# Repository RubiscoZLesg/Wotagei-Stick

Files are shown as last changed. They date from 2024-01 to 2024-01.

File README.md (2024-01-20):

# 可变色充电式电子荧光棒
WOTA艺打师永業参上！ 骗个关注先~ \
https://space.bilibili.com/18416307?spm_id_from=333.1007.0.0 \
因为目前市面上可充电电棒各有千秋（参差不齐），不是很符合个人平时练习需求，于是就自己做了个。 \
成本相当低廉，外壳使用了外径18mm，壁厚1.5mm，长20cm的透明PC管，PCB与3D打印零件均由嘉立创打样制作，如果领了券的话，一对大概能以20元价格拿下。 \
另外为了脱机控制颜色，制作了控制板，成本大概在5元左右，界面不甚优雅，突出一个能用就行。

## 光棒
主控采用了STC8G，驱动12颗WS2812灯珠，供电采用单节14500电池，长按开关机。为防止误触与增加稳定性，开关做在了顶部，但尺寸选的不太好（手里有于是就没买别的） \
为了保存颜色，MCU一旦上电就不会掉电，但整板采用了低功耗设计，静态功耗在uA级，充满电后也可以连续正常使用2小时以上。

- 光棒效果
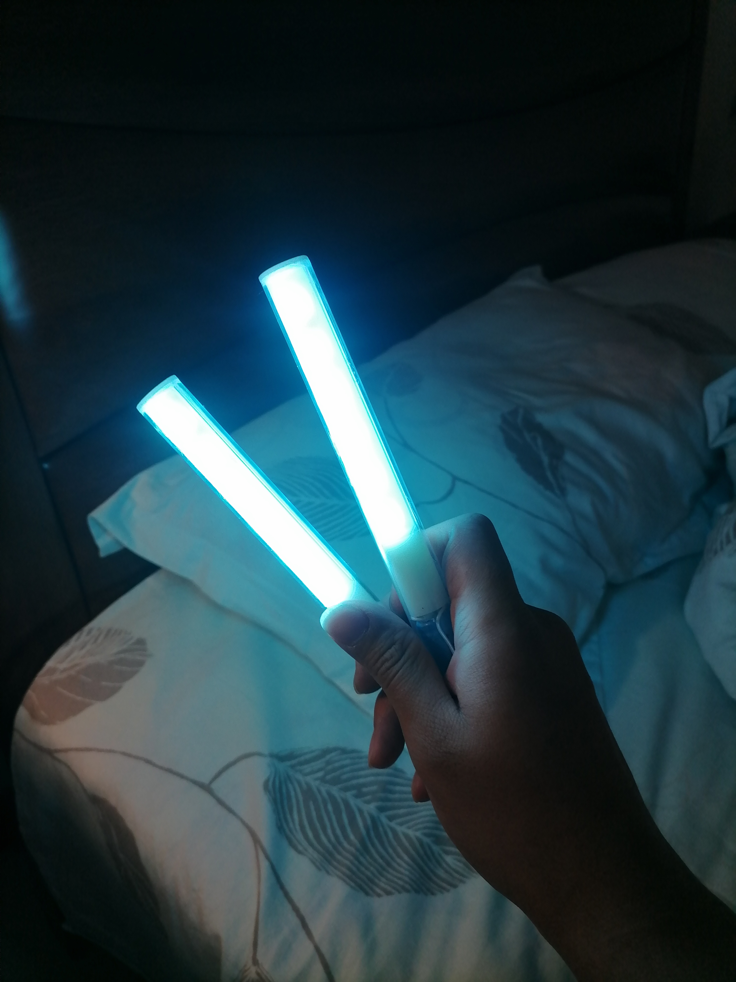
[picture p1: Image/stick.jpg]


- 充电效果
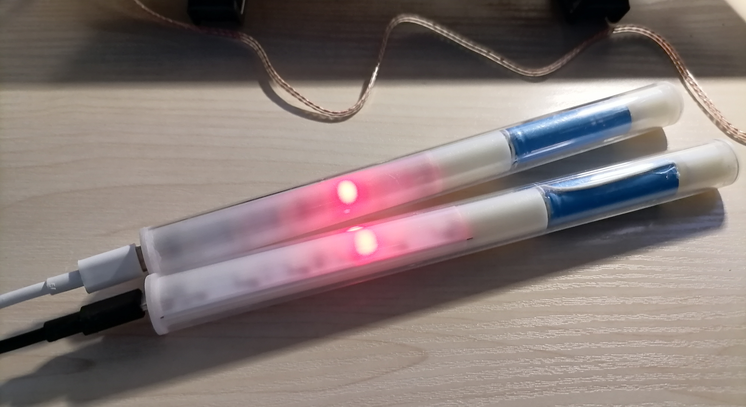
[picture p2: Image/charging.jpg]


- 灯板正反面
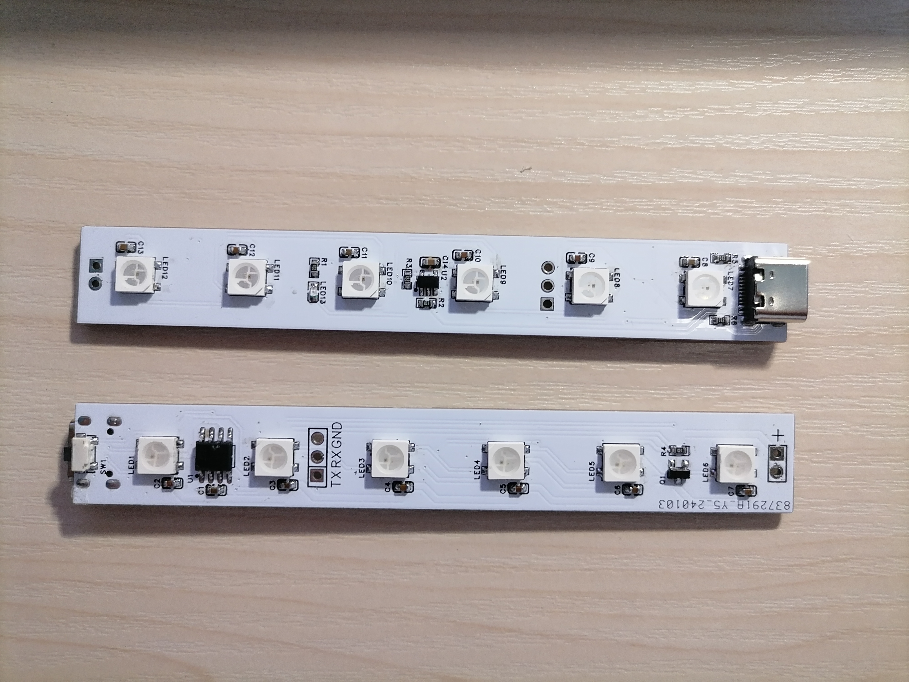
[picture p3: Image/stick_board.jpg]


## 控制板
主控采用了STM32G030，带一块0.96寸IPS，颜色控制数据传输采用了串口（USB两个数据线一根TX一根RX）,也是能充电的。

- 正面长这样
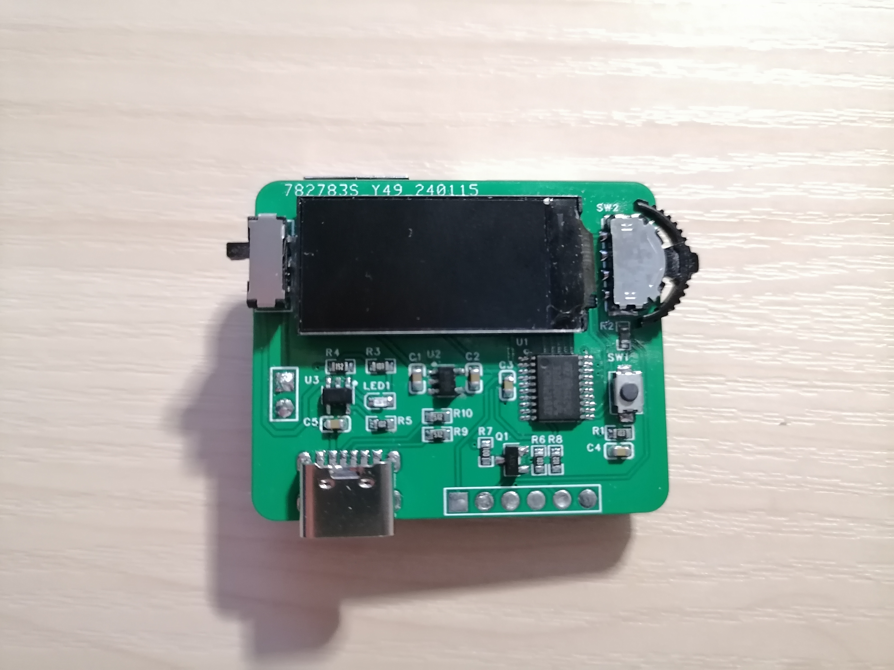
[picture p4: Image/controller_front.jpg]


- 背面长这样（TYPE-A座子再插TYPE-C线属实不够优雅，但手头刚好有而且好焊）
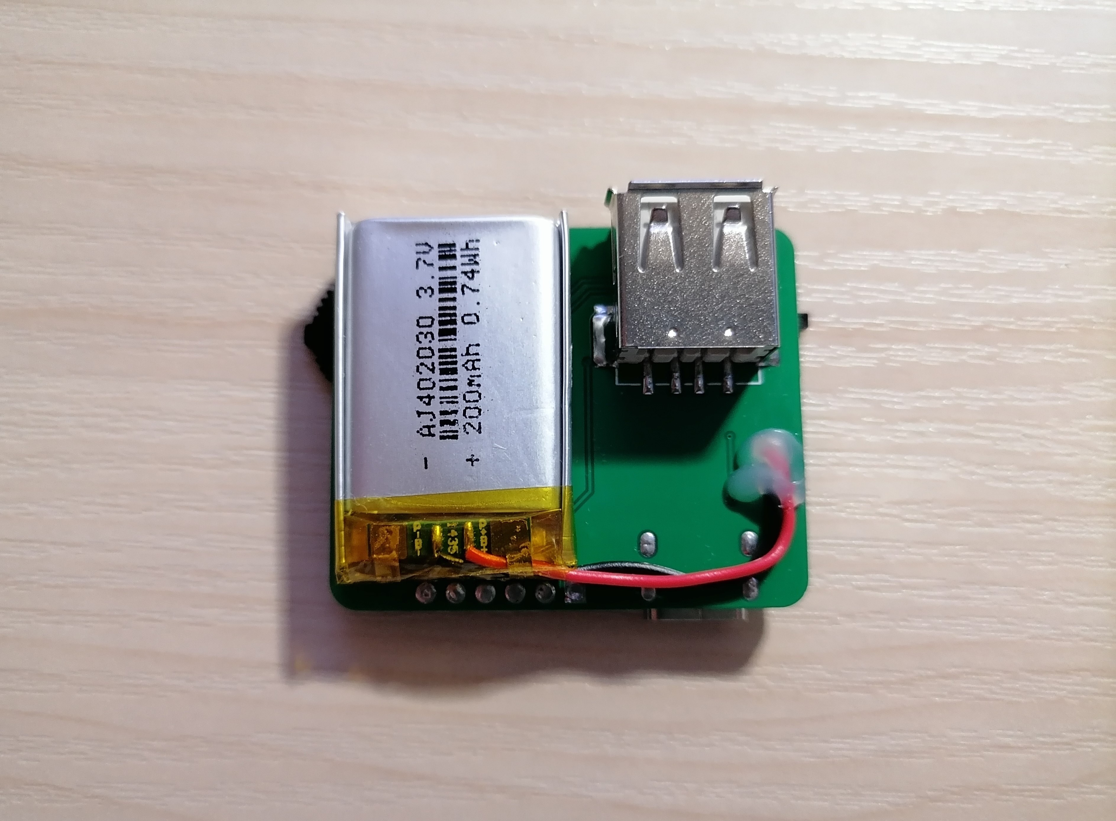
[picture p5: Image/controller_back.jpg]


- 屏幕界面
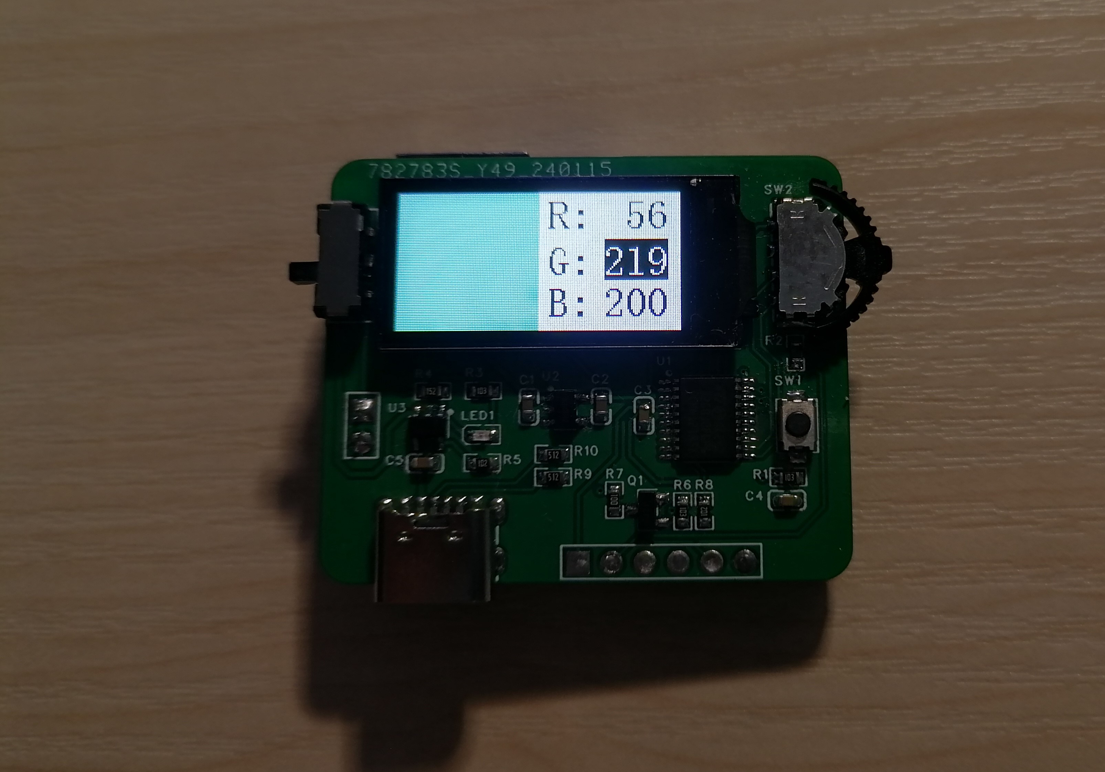
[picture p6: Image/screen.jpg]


## 制作方法
Gerber文件夹中有各个部分的Gerber文件，交付板厂就能直接打样，光棒灯板板厚要选`1.0mm`。 \
Model文件夹中是外壳零件的STL文件，可直接3D打印。 \
Frimware文件夹中是光棒的hex固件，使用`STC-ISP`烧录，烧录时工作频率选择`24MHz`。 \
Hardware文件夹中提供了立创EDA与AD（立创EDA导出的hh）两种PCB工程文件，方便各位查看。 \
Sourse中存放了源码（waring: 注释不多），分别是`Keil`与`STM32CubeIDE`工程文件，仅供参考，如有更好的实现方法欢迎交流。

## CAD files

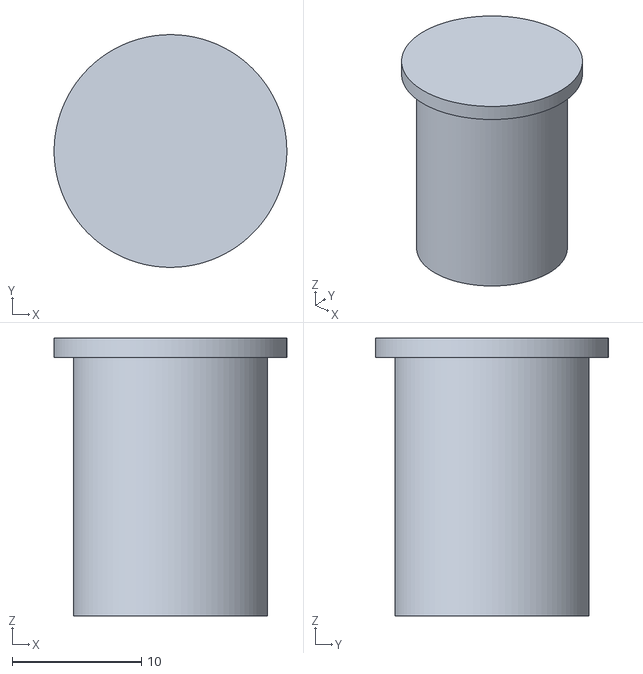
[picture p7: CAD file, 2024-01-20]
Model/3DShell_3DShell_WotageiStick_T_3.stl
18.0 x 18.0 x 21.5

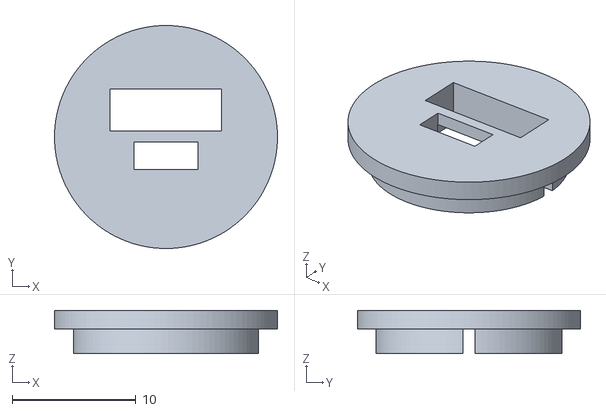
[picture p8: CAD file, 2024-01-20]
Model/3DShell_3DShell_WotageiStick_T_2.stl
18.0 x 18.0 x 3.50

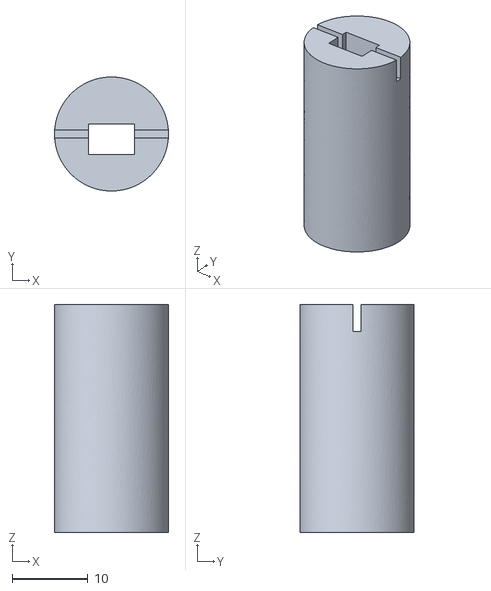
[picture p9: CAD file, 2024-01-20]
Model/3DShell_3DShell_WotageiStick_T_4.stl
15.0 x 15.0 x 30.0

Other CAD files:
Source/Wotagei_Stick/Objects/main.obj

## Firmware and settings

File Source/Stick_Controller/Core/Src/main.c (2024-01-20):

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
/* Includes ------------------------------------------------------------------*/
#include "main.h"
#include "spi.h"
#include "usart.h"
#include "gpio.h"

/* USER CODE BEGIN Includes */
#include "lcd_init.h"
#include "lcd.h"
#include "stdio.h"
/* USER CODE END Includes */


/* USER CODE BEGIN PV */
uint16_t Rdat = 255, Gdat, Bdat;
uint8_t State;
uint8_t Sel_Cnt;
uint8_t Sel_Flag = 1, Adj_Flag;
/* USER CODE END PV */

void SystemClock_Config(void);
/**
  * @brief  The application entry point.
  * @retval int
  */
int main(void)
{
  /* MCU Configuration--------------------------------------------------------*/

  /* Reset of all peripherals, Initializes the Flash interface and the Systick. */
  HAL_Init();

  /* Configure the system clock */
  SystemClock_Config();

  /* Initialize all configured peripherals */
  MX_GPIO_Init();
  MX_SPI1_Init();
  MX_USART1_UART_Init();
  /* USER CODE BEGIN 2 */
  LCD_Init();
  LCD_Fill(0, 0, LCD_W/2, LCD_H, RED);
  LCD_Fill(LCD_W/2-1, 0, LCD_W, LCD_H, WHITE);
  LCD_ShowString(LCD_W/2+5, 0, (uint8_t *)"R:", BLACK, WHITE, 24, 0);
  LCD_ShowString(LCD_W/2+5, 27, (uint8_t *)"G:", BLACK, WHITE, 24, 0);
  LCD_ShowString(LCD_W/2+5, 51, (uint8_t *)"B:", BLACK, WHITE, 24, 0);
  LCD_ShowIntNum(LCD_W/2+37, 0, Rdat, 3, WHITE, BLACK, 24);
  LCD_ShowIntNum(LCD_W/2+37, 27, Gdat, 3, BLACK, WHITE, 24);
  LCD_ShowIntNum(LCD_W/2+37, 51, Bdat, 3, BLACK, WHITE, 24);
  /* USER CODE END 2 */

  /* Infinite loop */
  /* USER CODE BEGIN WHILE */
  while (1)
  {
	  if (State == 0)
	  {
		  if (Sel_Flag)
		  {
			  Sel_Flag = 0;
			  switch (Sel_Cnt)
			  {
			  case 0:
				  LCD_ShowIntNum(LCD_W/2+37, 0, Rdat, 3, WHITE, BLACK, 24);
				  LCD_ShowIntNum(LCD_W/2+37, 27, Gdat, 3, BLACK, WHITE, 24);
				  LCD_ShowIntNum(LCD_W/2+37, 51, Bdat, 3, BLACK, WHITE, 24);
				  break;
			  case 1:
				  LCD_ShowIntNum(LCD_W/2+37, 0, Rdat, 3, BLACK, WHITE, 24);
				  LCD_ShowIntNum(LCD_W/2+37, 27, Gdat, 3, WHITE, BLACK, 24);
				  LCD_ShowIntNum(LCD_W/2+37, 51, Bdat, 3, BLACK, WHITE, 24);
				  break;
			  case 2:
				  LCD_ShowIntNum(LCD_W/2+37, 0, Rdat, 3, BLACK, WHITE, 24);
				  LCD_ShowIntNum(LCD_W/2+37, 27, Gdat, 3, BLACK, WHITE, 24);
				  LCD_ShowIntNum(LCD_W/2+37, 51, Bdat, 3, WHITE, BLACK, 24);
				  break;
			  }
		  }
	  }
	  else
	  {
		  if (Adj_Flag)
		  {
			  Adj_Flag = 0;
			  switch (Sel_Cnt)
			  {
			  case 0:
				  while (HAL_GPIO_ReadPin(SW_UP_GPIO_Port, SW_UP_Pin) == GPIO_PIN_RESET)
				  {
					  if (Rdat < 255)
					  {
						  Rdat++;
						  LCD_ShowIntNum(LCD_W/2+37, 0, Rdat, 3, WHITE, BLACK, 24);
						  LCD_Fill(0, 0, LCD_W/2, LCD_H, ((Rdat >> 3) << 11) + ((Gdat >> 2) << 5) + (Bdat >> 3));
					  }
				  }
				  while (HAL_GPIO_ReadPin(SW_DN_GPIO_Port, SW_DN_Pin) == GPIO_PIN_RESET)
				  {
					  if (Rdat > 0)
					  {
						  Rdat--;
						  LCD_ShowIntNum(LCD_W/2+37, 0, Rdat, 3, WHITE, BLACK, 24);
						  LCD_Fill(0, 0, LCD_W/2, LCD_H, ((Rdat >> 3) << 11) + ((Gdat >> 2) << 5) + (Bdat >> 3));
					  }
				  }
				  break;
			  case 1:
				  while (HAL_GPIO_ReadPin(SW_UP_GPIO_Port, SW_UP_Pin) == GPIO_PIN_RESET)
				  {
					  if (Gdat < 255)
					  {
						  Gdat++;
						  LCD_ShowIntNum(LCD_W/2+37, 27, Gdat, 3, WHITE, BLACK, 24);
						  LCD_Fill(0, 0, LCD_W/2, LCD_H, ((Rdat >> 3) << 11) + ((Gdat >> 2) << 5) + (Bdat >> 3));
					  }
				  }
				  while (HAL_GPIO_ReadPin(SW_DN_GPIO_Port, SW_DN_Pin) == GPIO_PIN_RESET)
				  {
					  if (Gdat > 0)
					  {
						  Gdat--;
						  LCD_ShowIntNum(LCD_W/2+37, 27, Gdat, 3, WHITE, BLACK, 24);
						  LCD_Fill(0, 0, LCD_W/2, LCD_H, ((Rdat >> 3) << 11) + ((Gdat >> 2) << 5) + (Bdat >> 3));
					  }
				  }
				  break;
			  case 2:
				  while (HAL_GPIO_ReadPin(SW_UP_GPIO_Port, SW_UP_Pin) == GPIO_PIN_RESET)
				  {
					  if (Bdat < 255)
					  {
						  Bdat++;
						  LCD_ShowIntNum(LCD_W/2+37, 51, Bdat, 3, WHITE, BLACK, 24);
						  LCD_Fill(0, 0, LCD_W/2, LCD_H, ((Rdat >> 3) << 11) + ((Gdat >> 2) << 5) + (Bdat >> 3));
					  }
				  }
				  while (HAL_GPIO_ReadPin(SW_DN_GPIO_Port, SW_DN_Pin) == GPIO_PIN_RESET)
				  {
					  if (Bdat > 0)
					  {
						  Bdat--;
						  LCD_ShowIntNum(LCD_W/2+37, 51, Bdat, 3, WHITE, BLACK, 24);
						  LCD_Fill(0, 0, LCD_W/2, LCD_H, ((Rdat >> 3) << 11) + ((Gdat >> 2) << 5) + (Bdat >> 3));
					  }
				  }
				  break;
			  }
		  }
	  }
    /* USER CODE END WHILE */

    /* USER CODE BEGIN 3 */
  }
  /* USER CODE END 3 */
}

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
/* USER CODE BEGIN 4 */
void HAL_GPIO_EXTI_Falling_Callback(uint16_t GPIO_Pin)
{
	uint8_t trans_buf[4] = {0};
	if(GPIO_Pin == SW_OK_Pin)
	{
		HAL_Delay(10);
        if (HAL_GPIO_ReadPin(SW_OK_GPIO_Port, SW_OK_Pin) == GPIO_PIN_RESET)
        {
        	if (State == 0)
        	{
        		State = 1;
        	}
        	else
        	{
        		State = 0;
        		trans_buf[0] = Rdat;
        		trans_buf[1] = Gdat;
        		trans_buf[2] = Bdat;
        		HAL_UART_Transmit(&huart1, trans_buf, 4, HAL_MAX_DELAY);
        	}

        }
	}
	else if(GPIO_Pin == SW_UP_Pin)
	{
		HAL_Delay(10);
        if (HAL_GPIO_ReadPin(SW_UP_GPIO_Port, SW_UP_Pin) == GPIO_PIN_RESET)
        {
        	if (State == 0)
        	{
        		if (Sel_Cnt > 0)
        		{
        			Sel_Flag = 1;
        			Sel_Cnt--;
        		}
        	}
        	else
        	{
        		Adj_Flag = 1;
        	}
        }
	}
	else if(GPIO_Pin == SW_DN_Pin)
	{
		HAL_Delay(10);
        if (HAL_GPIO_ReadPin(SW_DN_GPIO_Port, SW_DN_Pin) == GPIO_PIN_RESET)
        {
        	if (State == 0)
        	{
        		if (Sel_Cnt < 2)
        		{
        			Sel_Flag = 1;
        			Sel_Cnt++;
        		}
        	}
        	else
        	{
        		Adj_Flag = 1;
        	}
        }
	}
    __HAL_GPIO_EXTI_CLEAR_IT(GPIO_Pin);
}
/* USER CODE END 4 */
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


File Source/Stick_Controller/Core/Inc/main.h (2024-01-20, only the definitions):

#define IPS_CS_Pin GPIO_PIN_14
#define IPS_CS_GPIO_Port GPIOC
#define IPS_RES_Pin GPIO_PIN_15
#define IPS_RES_GPIO_Port GPIOC
#define IPS_DC_Pin GPIO_PIN_0
#define IPS_DC_GPIO_Port GPIOA
#define IPS_BLK_Pin GPIO_PIN_3
#define IPS_BLK_GPIO_Port GPIOA
#define SW_DN_Pin GPIO_PIN_4
#define SW_DN_GPIO_Port GPIOA
#define SW_DN_EXTI_IRQn EXTI4_15_IRQn
#define SW_OK_Pin GPIO_PIN_5
#define SW_OK_GPIO_Port GPIOA
#define SW_OK_EXTI_IRQn EXTI4_15_IRQn
#define SW_UP_Pin GPIO_PIN_6
#define SW_UP_GPIO_Port GPIOA
#define SW_UP_EXTI_IRQn EXTI4_15_IRQn

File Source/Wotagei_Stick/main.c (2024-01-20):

#include "stc8g.h"
#include "intrins.h"

unsigned char Light_Flag;
unsigned char Rdat = 0xFF, Gdat = 0x00, Bdat = 0x00;
unsigned char Rec_Cnt;

void Delay300us(void)	//@24.000MHz
{
	unsigned char data i, j;

	i = 10;
	j = 87;
	do
	{
		while (--j);
	} while (--i);
}

void Delay2000ms(void)	//@24.000MHz
{
	unsigned char data i, j, k;

	i = 244;
	j = 130;
	k = 4;
	do
	{
		do
		{
			while (--k);
		} while (--j);
	} while (--i);
}

void WS2812_Send_Bit(bit data_bit)
{
	if(data_bit)
	{
		P33 = 1;
		_nop_();_nop_();_nop_();_nop_();_nop_();_nop_();_nop_();
		_nop_();_nop_();_nop_();_nop_();_nop_();_nop_();_nop_();
		_nop_();_nop_();_nop_();_nop_();_nop_();_nop_();_nop_();
		P33 = 0;
		_nop_();_nop_();_nop_();_nop_();_nop_();_nop_();_nop_();
	}
	else
	{
		P33 = 1;
		_nop_();_nop_();_nop_();_nop_();_nop_();_nop_();_nop_();
		P33 = 0;
		_nop_();_nop_();_nop_();_nop_();_nop_();_nop_();_nop_();
		_nop_();_nop_();_nop_();_nop_();_nop_();_nop_();_nop_();
		_nop_();_nop_();_nop_();_nop_();_nop_();_nop_();_nop_();
	}
}

void WS2812_Rand_Color(unsigned char r,unsigned char g,unsigned char b)
{
	WS2812_Send_Bit(g&0x80);WS2812_Send_Bit(g&0x40);WS2812_Send_Bit(g&0x20);WS2812_Send_Bit(g&0x10);
	WS2812_Send_Bit(g&0x08);WS2812_Send_Bit(g&0x04);WS2812_Send_Bit(g&0x02);WS2812_Send_Bit(g&0x01);
	
	WS2812_Send_Bit(r&0x80);WS2812_Send_Bit(r&0x40);WS2812_Send_Bit(r&0x20);WS2812_Send_Bit(r&0x10);
	WS2812_Send_Bit(r&0x08);WS2812_Send_Bit(r&0x04);WS2812_Send_Bit(r&0x02);WS2812_Send_Bit(r&0x01);
	
	WS2812_Send_Bit(b&0x80);WS2812_Send_Bit(b&0x40);WS2812_Send_Bit(b&0x20);WS2812_Send_Bit(b&0x10);
	WS2812_Send_Bit(b&0x08);WS2812_Send_Bit(b&0x04);WS2812_Send_Bit(b&0x02);WS2812_Send_Bit(b&0x01);
}

void Uart1_Init(void)	//9600bps@24.000MHz
{
	SCON = 0x50;		//8位数据,可变波特率
	AUXR |= 0x40;		//定时器时钟1T模式
	AUXR &= 0xFE;		//串口1选择定时器1为波特率发生器
	TMOD &= 0x0F;		//设置定时器模式
	TL1 = 0x8F;			//设置定时初始值
	TH1 = 0xFD;			//设置定时初始值
	ET1 = 0;			//禁止定时器中断
	TR1 = 1;			//定时器1开始计时
	ES = 1;				//使能串口1中断
}

void main()
{
	unsigned char i;
	
	P0M0 = 0x00;
    P0M1 = 0x00;
    P1M0 = 0x00;
    P1M1 = 0x00;
    P2M0 = 0x00;
    P2M1 = 0x00;
    P3M0 = 0x00;
    P3M1 = 0x00;
    P4M0 = 0x00;
    P4M1 = 0x00;
    P5M0 = 0x00;
    P5M1 = 0x00;
	
	P55 = 1;
	P33 = 0;
	
    IT0 = 1;
    EX0 = 1;
	
	Uart1_Init();
	
	EA = 1;
	
	PCON = 0x02;
	_nop_();

	while (1)
	{
		if (P32 == 0)
		{
			Delay2000ms();
			if (P32 == 0)
			{
				Light_Flag = ~Light_Flag;
			}
		}
		
		if (Light_Flag)
		{
			P55 = 0;
			for(i = 0; i < 12; i++)
			{
				WS2812_Rand_Color(Rdat, Gdat, Bdat);
			}
			P33 = 0;
			Delay300us();
		}
		else
		{
			P55 = 1;
			PCON = 0x02;
			_nop_();
		}
	}
}

void INT0_Isr() interrupt 0 
{

}

void Uart1_Isr(void) interrupt 4
{
	if (RI)				//检测串口1接收中断
	{
		RI = 0;			//清除串口1接收中断请求位
		switch (Rec_Cnt)
		{
			case 0:
				Rdat = SBUF;
				Rec_Cnt++;
				break;
			case 1:
				Gdat = SBUF;
				Rec_Cnt++;
				break;
			case 2:
				Bdat = SBUF;
				Rec_Cnt++;
				break;
			default:
				Rec_Cnt = 0;
				break;
		}
		
	}
}

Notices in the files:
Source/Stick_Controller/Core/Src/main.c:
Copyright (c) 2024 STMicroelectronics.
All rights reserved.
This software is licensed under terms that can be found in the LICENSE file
